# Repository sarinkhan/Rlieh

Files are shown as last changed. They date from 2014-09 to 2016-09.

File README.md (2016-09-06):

Rlieh
=====

Remote Location Intelligent Ecosystem Handler - a system to manage closed ecosystems such as aquariums or terrariums.
This relies on open source and open hardware technologies. It's meant to be modular, not too expensive, and yet powerful.
Feel free to consult the [Rlieh wiki](https://github.com/sarinkhan/Rlieh/wiki) for more!

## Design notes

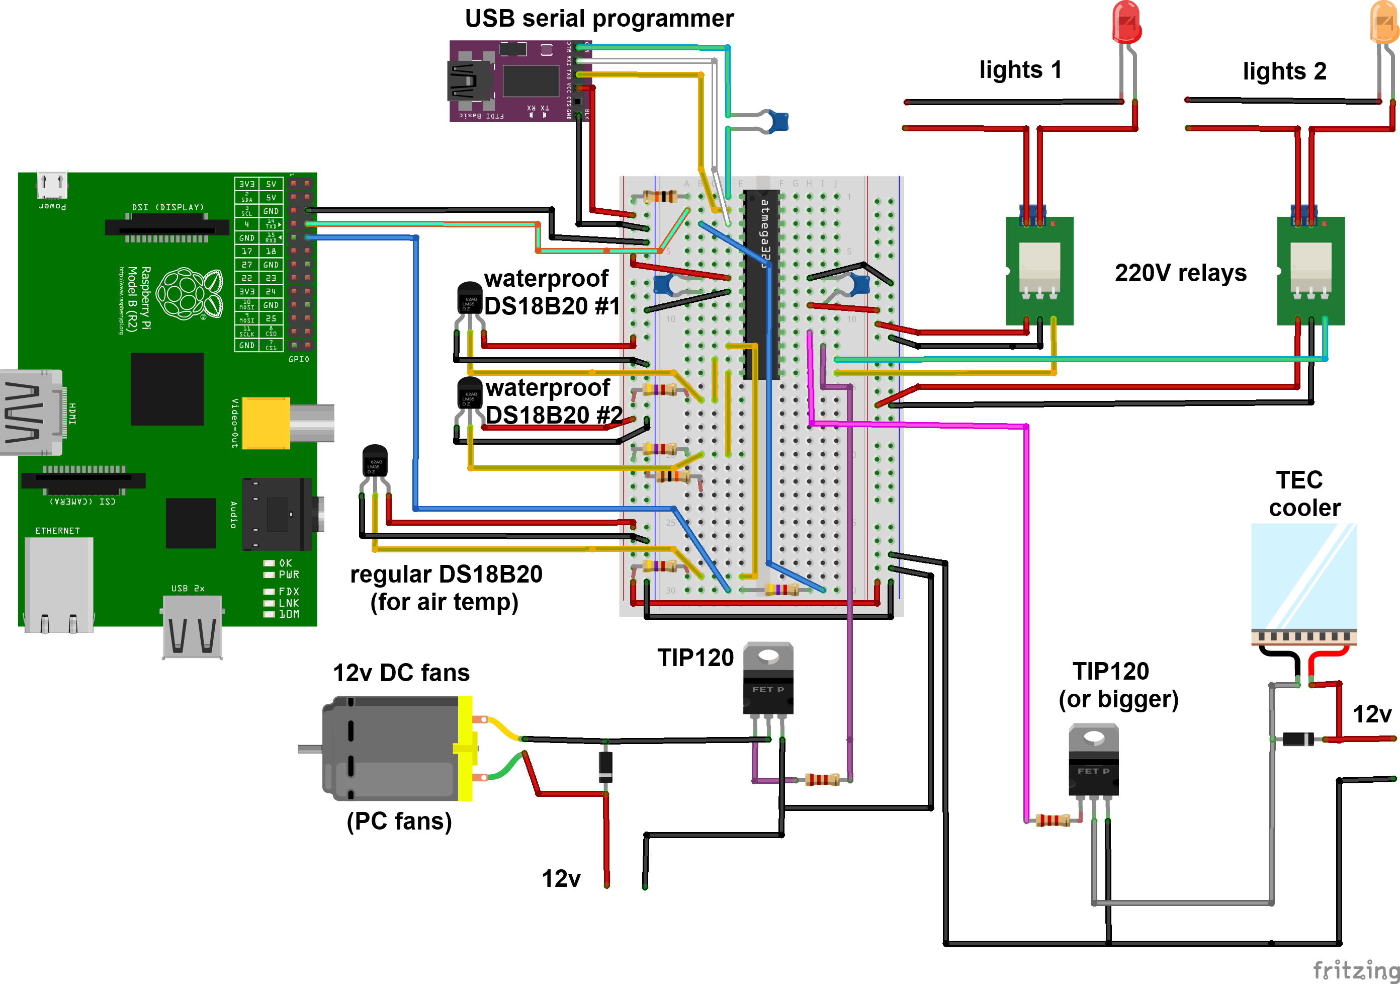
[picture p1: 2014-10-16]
fritzing/base_circuit02_annotations.png

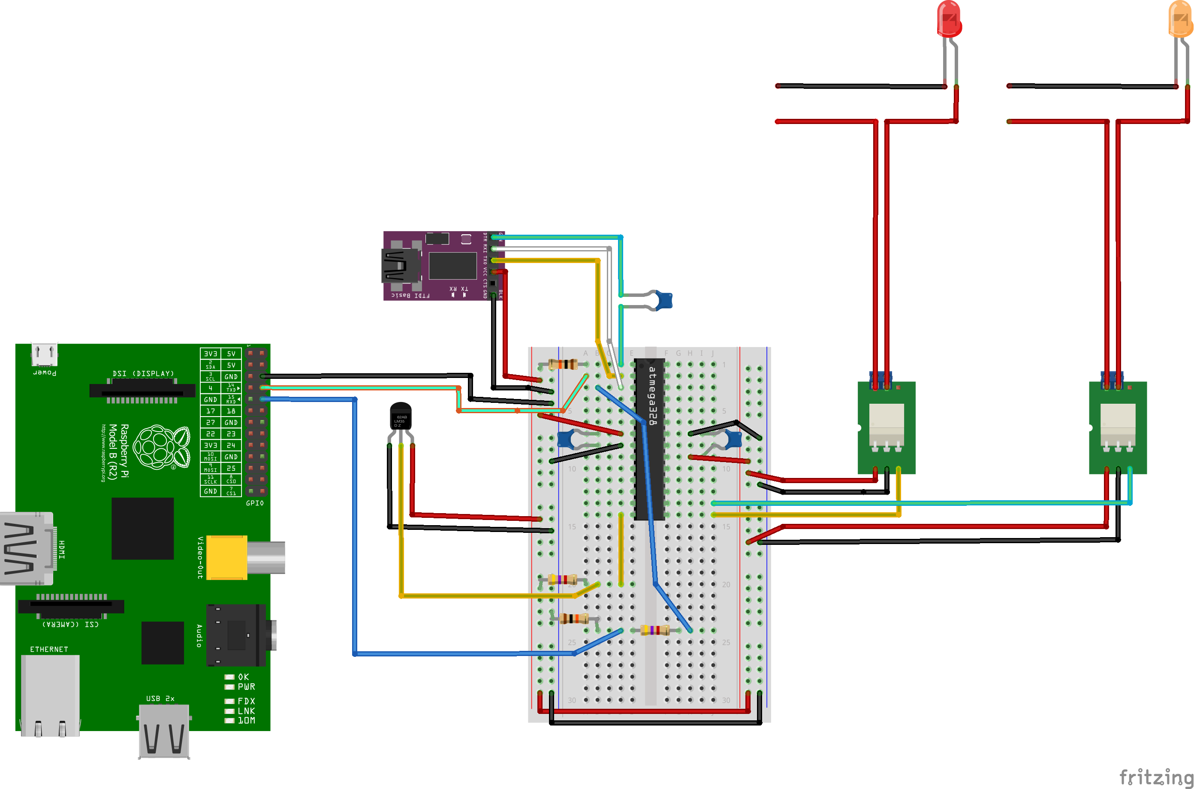
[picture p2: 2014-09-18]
fritzing/base_circuit01.png

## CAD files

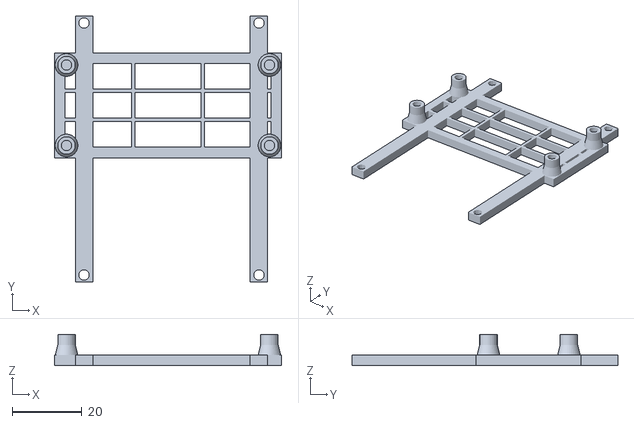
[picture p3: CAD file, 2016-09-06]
enclosure/piZeroSimpleSupportBottom.stl
65.0 x 76.0 x 9.00

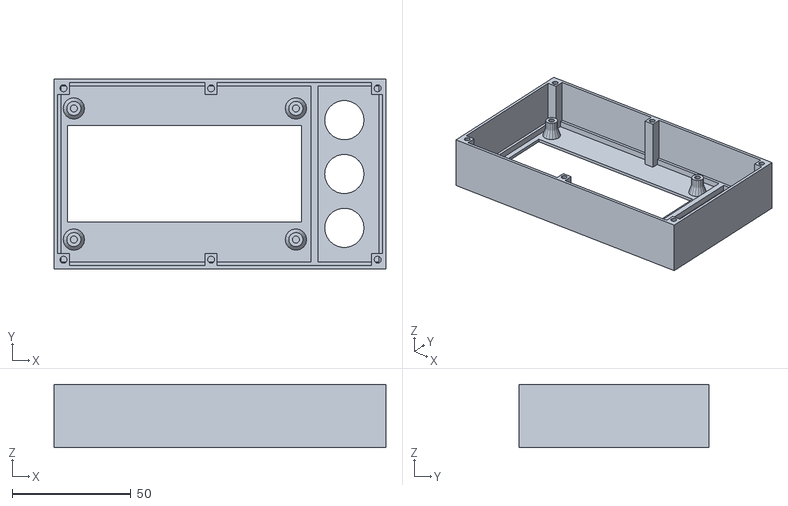
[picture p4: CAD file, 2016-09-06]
enclosure/controlBox.stl
139.5 x 80.0 x 26.5

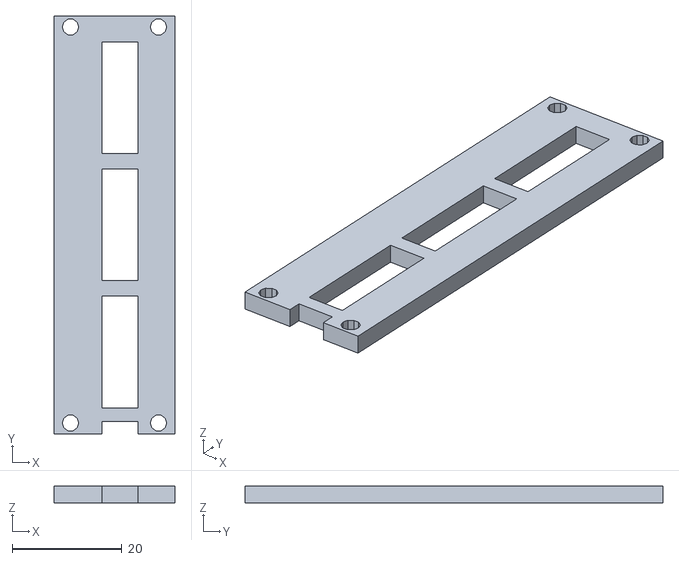
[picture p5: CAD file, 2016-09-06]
enclosure/frontLedsDiffuserCenteringPlate.stl
22.0 x 76.0 x 3.00

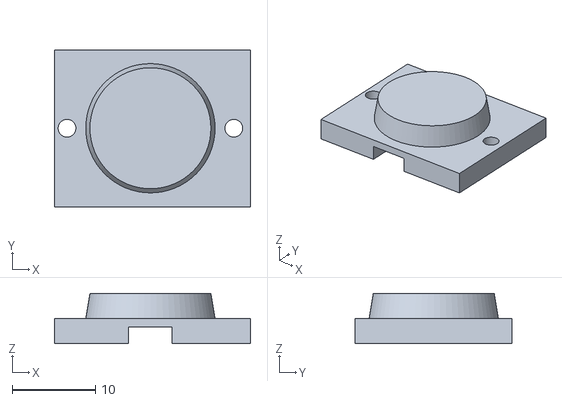
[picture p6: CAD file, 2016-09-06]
enclosure/frontLedDiffuserButton.stl
23.5 x 18.8 x 6.00

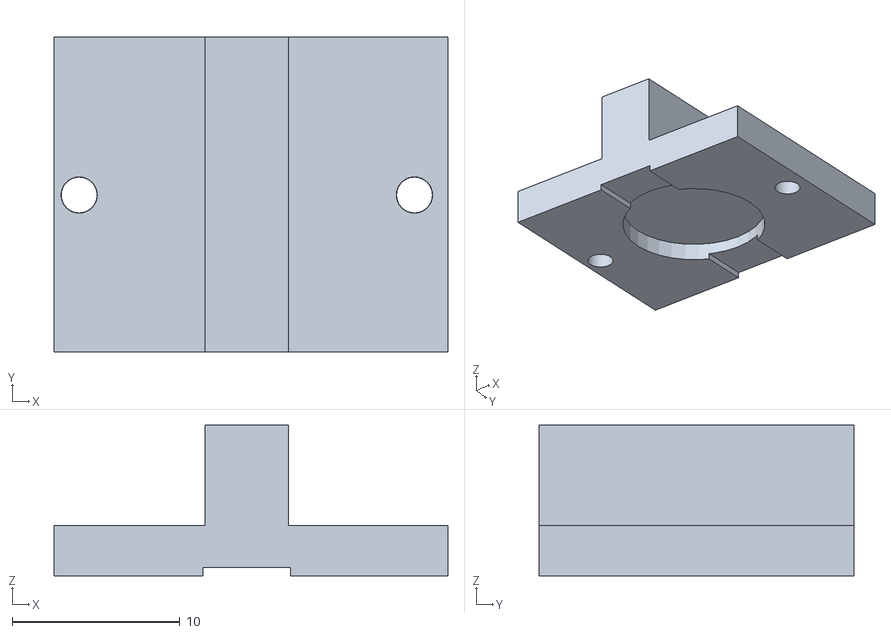
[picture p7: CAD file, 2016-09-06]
enclosure/frontLedDiffuserButtonBack.stl
23.5 x 18.8 x 9.00

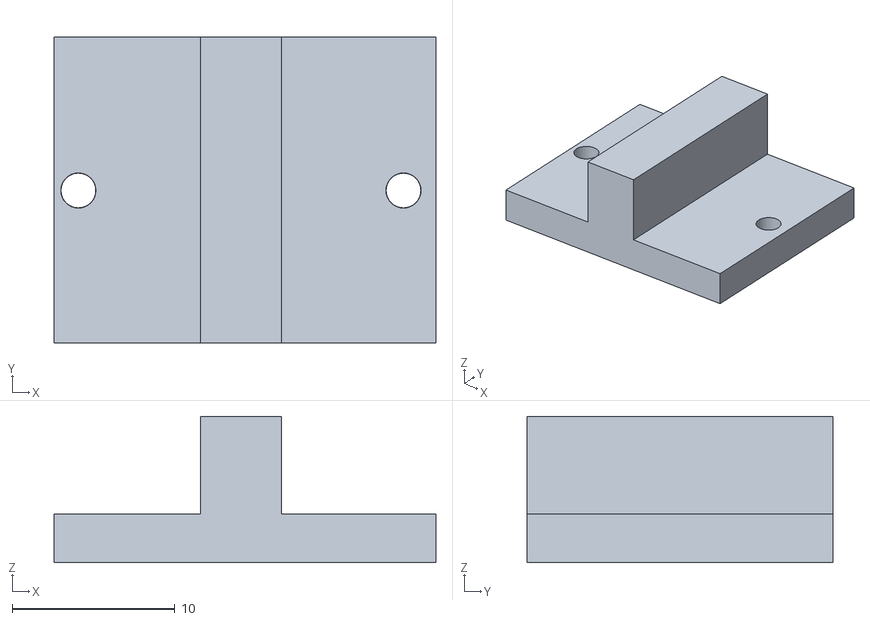
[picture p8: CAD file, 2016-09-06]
enclosure/ledDiffuserBackPlate.stl
23.5 x 18.8 x 9.00

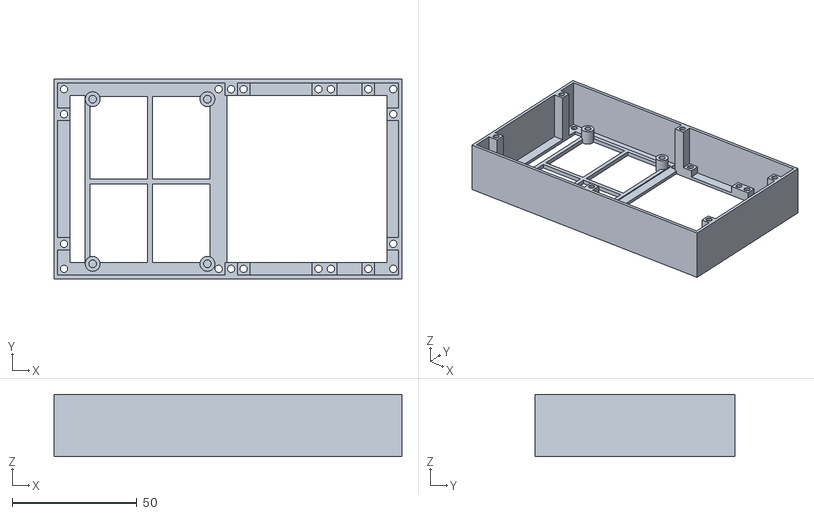
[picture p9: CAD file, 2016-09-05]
enclosure/faceBox_layer2.stl
139.5 x 80.0 x 25.0

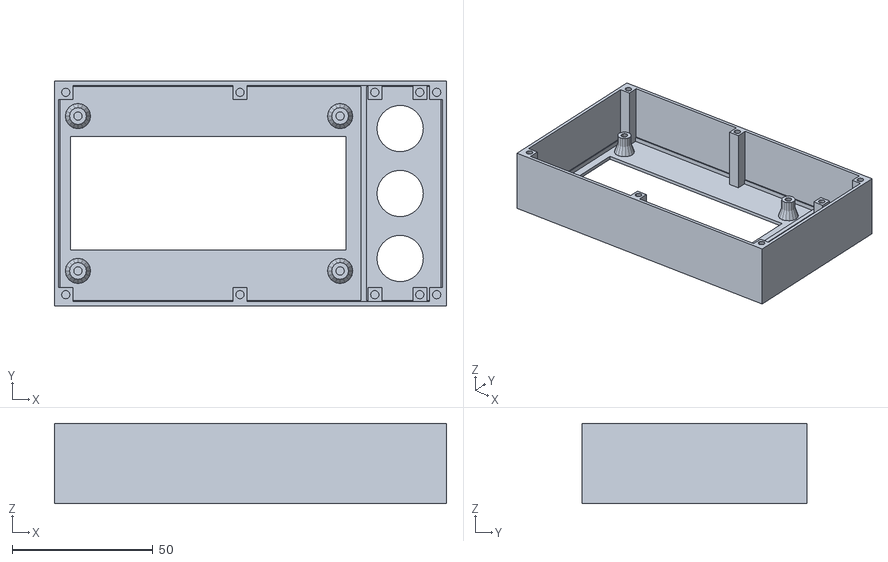
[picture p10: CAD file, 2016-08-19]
enclosure/faceBox.stl
139.5 x 80.0 x 28.5

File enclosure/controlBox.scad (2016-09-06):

include<../parts/textLcdBezels.scad>


//bezel4x20X=110;
bezel4x20Y=80;

boxWallsThickness=1.5;
buttonsAreaX=30;

buttonsHoleRadius=16.5/2;
beamsThickness=3;

boxPart1Z=25;
screwHoles1Radius=3/2;
pillarsWidth1=5;

module fixationPillar(pillarWidth=pillarsWidth1,pillarHeight=boxPart1Z,pillarScrewRadius=screwHoles1Radius)
{
    difference()
    {
    cube([pillarWidth,pillarWidth,pillarHeight]);
        translate([pillarWidth/2,pillarWidth/2,1])
        cylinder(r=pillarScrewRadius,h=pillarHeight,$fn=12);
    } 
}

nbButtons=3;
buttonDecalX=(buttonsAreaX-beamsThickness*2-1)/2;
buttonDecalY=(bezel4x20Y-beamsThickness*2-nbButtons*buttonsHoleRadius*2)/(nbButtons+1);
echo (buttonDecalY);
bezel4x20(bezel4x20X,bezel4x20Y,boxWallsThickness,3/2);
translate([bezel4x20X-0.5,0,0])
{
    difference()
    {
        cube([buttonsAreaX,bezel4x20Y,boxWallsThickness]);
        for(i = [1 : 1 : nbButtons])
        {
            translate([buttonDecalX+1,beamsThickness+buttonDecalY*i+buttonsHoleRadius+buttonsHoleRadius*2*(i-1),-boxWallsThickness/2])
                cylinder(r=buttonsHoleRadius,h=boxWallsThickness*2);
        }
        
        /*translate([buttonDecalX+1,27,-boxWallsThickness/2])
            cylinder(r=buttonsHoleRadius,h=boxWallsThickness*2);
        translate([buttonDecalX+1,55,-boxWallsThickness/2])
            cylinder(r=buttonsHoleRadius,h=boxWallsThickness*2);*/
        
    }
}

//beams
translate([0,0,boxWallsThickness])
    cube([bezel4x20X+buttonsAreaX-0.5,beamsThickness,beamsThickness]);
translate([0,bezel4x20Y-beamsThickness,boxWallsThickness])
    cube([bezel4x20X+buttonsAreaX-0.5,beamsThickness,beamsThickness]);

translate([0,0,boxWallsThickness])
    cube([beamsThickness,bezel4x20Y,beamsThickness]);
translate([bezel4x20X+buttonsAreaX-beamsThickness-0.5,0,boxWallsThickness])
    cube([beamsThickness,bezel4x20Y,beamsThickness]);

translate([bezel4x20X-beamsThickness+1,0,boxWallsThickness])
    cube([beamsThickness,bezel4x20Y,beamsThickness]);

//walls
translate([0,0,boxWallsThickness])
    cube([bezel4x20X+buttonsAreaX-0.5,boxWallsThickness,boxPart1Z]);
translate([0,bezel4x20Y-boxWallsThickness,boxWallsThickness])
    cube([bezel4x20X+buttonsAreaX-0.5,boxWallsThickness,boxPart1Z]);
translate([0,0,boxWallsThickness])
    cube([boxWallsThickness,bezel4x20Y,boxPart1Z]);
translate([bezel4x20X+buttonsAreaX-boxWallsThickness-0.5,0,boxWallsThickness])
    cube([boxWallsThickness,bezel4x20Y,boxPart1Z]);

//pillars
translate([boxWallsThickness,boxWallsThickness,boxWallsThickness])    
    fixationPillar();
translate([bezel4x20X+buttonsAreaX-pillarsWidth1-boxWallsThickness,boxWallsThickness,boxWallsThickness])    
    fixationPillar();


translate([(bezel4x20X+buttonsAreaX)/2-pillarsWidth1-boxWallsThickness,bezel4x20Y-pillarsWidth1-boxWallsThickness,boxWallsThickness])    
    fixationPillar();
translate([(bezel4x20X+buttonsAreaX)/2-pillarsWidth1-boxWallsThickness,boxWallsThickness,boxWallsThickness])    
    fixationPillar();

    
translate([boxWallsThickness,bezel4x20Y-pillarsWidth1-boxWallsThickness,boxWallsThickness])    
    fixationPillar();
translate([bezel4x20X+buttonsAreaX-pillarsWidth1-boxWallsThickness,bezel4x20Y-pillarsWidth1-boxWallsThickness,boxWallsThickness])    
    fixationPillar();

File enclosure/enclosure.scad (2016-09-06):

battSlotsSpacingX=1;
beamsThickness2=5;
firstStageHeight=28;

include<../parts/lipoBattHolder.scad>
include<waterproofBox.scad>
include<../parts/rpiPlate5_halfFlatMount_mod.scad>




//constraints : these are the minimal internal dimensions of the box
insideBoxMinX=basicBattHolderLength;
insideBoxMinY=83+2*beamsThickness2;
insideBoxMinZ=72;




//if you want to alter the box size, change the values here, keeping the min sizes and adding a value : 
insideBoxX1=insideBoxMinX+battSlotsSpacingX*2+25;
insideBoxY1=insideBoxMinY+0;
insideBoxZ1=insideBoxMinZ+0;


boxSealingLipWidth=8;
boxLipThickness=2;




echo ("inside box X : ");
echo(insideBoxX1);
echo ("inside box Y : ");
echo(insideBoxY1);
echo ("inside box Z : ");
echo(insideBoxZ1);

//basicBattHolderWidth
boxWallsThickness1=1;
boxSealingLipWidth=beamsThickness2;
screwHoles1Radius=3/2;



secondStageDecal=0.5;


cameraHoleRadius=20/2;
cameraHoleZDecal=5;
cameraSkirtSupportThickness=7;
cameraSkirtSupportBaseWidth=cameraHoleRadius*2+20;
cameraSkirtSupportBaseHeight=cameraSkirtSupportBaseWidth;
cameraSkirtSupportDecalY=(cameraSkirtSupportBaseWidth-cameraHoleRadius*2)/2;
cameraSkirtSupportDecalZ=(cameraSkirtSupportBaseHeight-cameraHoleRadius*2)/2;
cameraSkirtSupportScrewHolesDistFromEdge=4;

cameraHole=1;   //set to 1 for a camera hole, 0 for no hole

buttonsHoles=1; //set to 1 for button holes, 0 for no hole
buttonsHolesRadius=16.8/2;
buttonsCount1=3;
buttonsMargin1=5;

totalBoundingBoxX=insideBoxX1+2*boxWallsThickness1+2*boxSealingLipWidth;
totalBoundingBoxY=insideBoxY1+2*boxWallsThickness1+2*boxSealingLipWidth;
totalBoundingBoxZ=insideBoxZ1+boxWallsThickness1+0;//define


frontOpeningRadius=buttonsHolesRadius;
frontOpeningsPlateX=cameraSkirtSupportThickness;
frontOpeningsPlateY=frontOpeningRadius*2+10;
frontOpeningsPlateZ=frontOpeningsPlateY;
frontOpeningsholesDistFromEdge=3;
frontOpening1=1;
frontOpening2=1;
frontOpeningDecalZ=firstStageHeight+beamsThickness2+5;


frontOpeningsGasketThickness=1.5;
frontOpeningsLidThickness=4;



sideOpeningRadius=frontOpeningRadius;
sideOpeningsPlateX=frontOpeningsPlateX;
sideOpeningsPlateY=frontOpeningsPlateY;
sideOpeningsPlateZ=frontOpeningsPlateZ;
sideOpeningsholesDistFromEdge=frontOpeningsholesDistFromEdge;
sideOpening1=1;
sideOpening2=1;
sideOpeningDecalZ=frontOpeningDecalZ;


backOpenings1=1;
backOpenings2=1;
backOpeningsCount=3;
backOpeningRadius=frontOpeningRadius;
backOpeningsPlateX=frontOpeningsPlateX;
backOpeningsPlateY=frontOpeningsPlateY;
backOpeningsPlateZ=frontOpeningsPlateZ;
backOpeningsholesDistFromEdge=frontOpeningsholesDistFromEdge;
backOpening1DecalZ=frontOpeningDecalZ;
backOpening2DecalZ=2;
backOpenings1Count=3;
backOpenings2Count=3;



/**
 * This module constructs a circular opening with a support base, and 4 screwholes in each corner
 */
module openingWithSupport1(centralOpeningRadius=buttonsHolesRadius,frFixHolesRad=screwHoles1Radius,baseX,baseY,baseZ,holesDistFromEdge)
{
    difference()
    {
        cube([baseX,baseY,baseZ]);
        translate([-baseX/2,baseY/2,baseZ/2])
            rotate([0,90,0])
                cylinder(r=centralOpeningRadius,h=baseX*2,$fn=64);
        
       translate([-baseX/2,holesDistFromEdge,holesDistFromEdge])
            rotate([0,90,0])
                cylinder(r=frFixHolesRad,h=baseX*2,$fn=16);
       translate([-baseX/2,baseY-holesDistFromEdge,holesDistFromEdge])
            rotate([0,90,0])
                cylinder(r=frFixHolesRad,h=baseX*2,$fn=16);
       translate([-baseX/2,holesDistFromEdge,baseZ-holesDistFromEdge])
            rotate([0,90,0])
                cylinder(r=frFixHolesRad,h=baseX*2,$fn=16);
       translate([-baseX/2,baseY-holesDistFromEdge,baseZ-holesDistFromEdge])
            rotate([0,90,0])
                cylinder(r=frFixHolesRad,h=baseX*2,$fn=16);
    }
}
module openingWithSupport1WithSlope(centralOpeningRadius=buttonsHolesRadius,frFixHolesRad=screwHoles1Radius,baseX,baseY,baseZ,holesDistFromEdge)
{
   openingWithSupport1(centralOpeningRadius,frFixHolesRad,baseX,baseY,baseZ,holesDistFromEdge);
    translate([baseX,baseY,0])
            rotate([90,-180,0])
                triangleSupport(baseX,baseX,baseY);
    
}

module openingLid(frFixHolesRad=screwHoles1Radius,baseX,baseY,baseZ,holesDistFromEdge)
{
    difference()
    {
        cube([baseX,baseY,baseZ]);
       translate([-baseX/2,holesDistFromEdge,holesDistFromEdge])
            rotate([0,90,0])
                cylinder(r=frFixHolesRad,h=baseX*2,$fn=16);
       translate([-baseX/2,baseY-holesDistFromEdge,holesDistFromEdge])
            rotate([0,90,0])
                cylinder(r=frFixHolesRad,h=baseX*2,$fn=16);
       translate([-baseX/2,holesDistFromEdge,baseZ-holesDistFromEdge])
            rotate([0,90,0])
                cylinder(r=frFixHolesRad,h=baseX*2,$fn=16);
       translate([-baseX/2,baseY-holesDistFromEdge,baseZ-holesDistFromEdge])
            rotate([0,90,0])
                cylinder(r=frFixHolesRad,h=baseX*2,$fn=16);
    }
}

module cameraSkirtBaseShape()
{
    openingWithSupport1(buttonsHolesRadius,screwHoles1Radius,cameraSkirtSupportThickness,cameraSkirtSupportBaseWidth,cameraSkirtSupportBaseHeight,cameraSkirtSupportScrewHolesDistFromEdge);
}

module cameraSkirt()
{
    cameraSkirtBaseShape();
}


module cameraSkirtBaseShapeWithSlope()
{
    cameraSkirtBaseShape();
    translate([cameraSkirtSupportThickness,cameraSkirtSupportBaseWidth,0])
            rotate([90,-180,0])
                triangleSupport(cameraSkirtSupportThickness,cameraSkirtSupportThickness,cameraSkirtSupportBaseWidth);
}
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

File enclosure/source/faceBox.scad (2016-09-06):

include<textLcdBezels.scad>
use<rpiPlateCompact1.scad>





//bezel4x20X=110;
bezel4x20Y=80;

boxWallsThickness=1.5;
buttonsAreaX=30;

buttonsHoleRadius=16.5/2;         
beamsThickness=3;

boxPart1Z=27;
boxPart2Z=25;
boxPart3Z=25;
screwHoles1Radius=3/2;
pillarsWidth1=5;

/*
battBoxX=100;
battBoxY=95;
battBoxWallsThickness=1;

battBoxWallsHeight=20;
battBoxWalls2Height=30;
*/

fixationBeamsThickness=5;
fixationBeamsHolesRadius=3/2;

/*
pcbX=40;
pcbY=60;*/

pcbHolesDistFromEdge=2;

beamsThickness=2.0;
circuit1X=50;
circuit1Y=70;
circuit1ScrewsRadius=2/2;
circuit1ScrewsDistFromEdge=1;
circuit1ScrewPillarsH=5+beamsThickness;
screwHolesRadius=2/2;
padding=0.1;

buttonPlatePillarsHeight=8;

alertBoxExternalX=bezel4x20X+buttonsAreaX-0.5;
alertBoxInternalX1=alertBoxExternalX-boxWallsThickness*2;
alertBoxInternalX2=alertBoxInternalX1-pillarsWidth1*2;

alertBoxExternalY=bezel4x20Y;
alertBoxInternalY1=alertBoxExternalY-boxWallsThickness*2;
alertBoxInternalY2=alertBoxInternalY1-pillarsWidth1*2;

boxInternalPadding=0.5;





nbButtons=3;
buttonDecalX=(buttonsAreaX-beamsThickness*2-1)/2;
buttonDecalY=(bezel4x20Y-beamsThickness*2-nbButtons*buttonsHoleRadius*2)/(nbButtons+1);
echo (buttonDecalY);

diffuserCentralHoleR=7.2/2;
    diffuserCentralHoleR2=12/2;
    diffuserLedCompartmentDepth=2;
    diffuserWireChanelWidth=5.2;
    diffuserBaseX=buttonsAreaX-1-5-0.5;
    diffuserBaseY=buttonsHoleRadius*2+buttonDecalY/2-1;
    diffuserBaseThickness=3;
    diffuserButtonCylinderZ=3;

    diffuserBackPlateFootX=5;
    diffuserBackPlateFootY=diffuserBaseY;
    diffuserBackPlateFootZ=6;
    
    
    piZeroHolesDistFromEdge=3.5;
    piZeroHolesRadius=2.75/2;
    
    piZeroLongSideHolesDist=58;
    piZeroShortSideHolesDist=23;
    
    piZeroLongSide=65;
    piZeroShortSide=30;
    
    
    
    module genericStandoff(holeRadius=3/2,standoffThickness=1,footHeight=3,footMultiplier=1.3,standoffTotalHeight=6,baseFootThickness=0,fn=32)
    {
        difference()
        {
        union()
        {
            translate([0,0,baseFootThickness])
            {
            cylinder(r1=(holeRadius+standoffThickness)*footMultiplier, r2=(holeRadius+standoffThickness),h=footHeight,$fn=fn);
            cylinder(r=(holeRadius+standoffThickness),h=standoffTotalHeight,$fn=fn);
            }
            if(baseFootThickness>0)
            {
                cylinder(r=(holeRadius+standoffThickness)*footMultiplier,h=baseFootThickness,$fn=fn);
            }
        }
        translate([0,0,baseFootThickness])
        cylinder(r=holeRadius,h=standoffTotalHeight+1,$fn=fn);
    }
        
    }
    
    
    //genericStandoff(baseFootThickness=3);
    
    
    module genericSupportFrame(outerFrameX,outerFrameY,frameThickness=3,frameBracesCountX=2,frameBracesCountY=2,framebracesThickness=1)
    {
        cube([outerFrameX,frameThickness,frameThickness]);
        cube([frameThickness,outerFrameY,frameThickness]);
        translate([0,outerFrameY-frameThickness,0])
            cube([outerFrameX,frameThickness,frameThickness]);
        translate([outerFrameX-frameThickness,0,0])
            cube([frameThickness,outerFrameY,frameThickness]);
        
        insideFrameFreeSpaceX=outerFrameX-(frameThickness*2)-frameBracesCountX*framebracesThickness;
        bracesSpacingX=insideFrameFreeSpaceX/(frameBracesCountX+1);
        
        if(frameBracesCountX>0)
        {
            for (i =[1:frameBracesCountX])
            {
                translate([frameThickness+(bracesSpacingX)*i+framebracesThickness*(i-1),0,0])
                    cube([framebracesThickness,outerFrameY,frameThickness]);
            }
        }
        
        insideFrameFreeSpaceY=outerFrameY-(frameThickness*2)-frameBracesCountY*framebracesThickness;
        bracesSpacingY=insideFrameFreeSpaceY/(frameBracesCountY+1);
        
        if(frameBracesCountY>0)
        {
            for (i =[1:frameBracesCountY])
            {
                translate([0,frameThickness+(bracesSpacingY)*i+framebracesThickness*(i-1),0])
                    cube([outerFrameX,framebracesThickness,frameThickness]);
            }
        }
    }
    
    module piZeroSimplePlate(frameThickness1=3,frameBracesCountX1=2,frameBracesCountY1=2,framebracesThickness1=1)
    {
        genericSupportFrame(outerFrameX=piZeroLongSide,outerFrameY=piZeroShortSide,frameThickness=frameThickness1,frameBracesCountX=frameBracesCountX1,frameBracesCountY=frameBracesCountY1,framebracesThickness=framebracesThickness1);
        
        
        
        translate([piZeroHolesDistFromEdge,piZeroHolesDistFromEdge,0])
        genericStandoff(baseFootThickness=frameThickness1);
        
        translate([piZeroHolesDistFromEdge,piZeroHolesDistFromEdge+piZeroShortSideHolesDist,0])
        genericStandoff(baseFootThickness=frameThickness1);
        
        translate([piZeroHolesDistFromEdge+piZeroLongSideHolesDist,piZeroHolesDistFromEdge,0])
        genericStandoff(baseFootThickness=frameThickness1);
        
        translate([piZeroHolesDistFromEdge+piZeroLongSideHolesDist,piZeroHolesDistFromEdge+piZeroShortSideHolesDist,0])
        genericStandoff(baseFootThickness=frameThickness1);
    }

    //genericSupportFrame(outerFrameX=60,outerFrameY=30);
    








module fixationPillar(pillarWidth=pillarsWidth1,pillarHeight=boxPart1Z,pillarScrewRadius=screwHoles1Radius)
{
    difference()
    {
    cube([pillarWidth,pillarWidth,pillarHeight]);
        translate([pillarWidth/2,pillarWidth/2,1])
        cylinder(r=pillarScrewRadius,h=pillarHeight,$fn=12);
    } 
}

module openBasePlate(x,y,nbBeamsX=3,nbBeamsY=2)
{
	xShift=x/(nbBeamsX+1);
	for (i =[0:nbBeamsX+1])
	{
		translate([xShift*i,0,0])
			cube([beamsThickness,y,beamsThickness]);
	}


	yShift=y/(nbBeamsY+1);
	for (i =[0:nbBeamsY+1])
	{
		translate([0,yShift*i,0])
			cube([x+beamsThickness,beamsThickness,beamsThickness]);
	}
}
module motorBracketHole(h0=boxPart1Z-beamsThickness,shift=beamsThickness,r0=screwHolesRadius) 
{
	translate([0,0,padding+shift]) 
	{
    	cylinder(r=3.1/2, h0+padding, center = false,$fn=32);
	}
}

module circuit1Plate()
{

	openBasePlate(circuit1X,circuit1Y,1,1);
    
    rrr0=3;

	translate([beamsThickness+circuit1ScrewsDistFromEdge,beamsThickness+circuit1ScrewsDistFromEdge,0])
		difference()
		{
			cylinder(r=rrr0,h=circuit1ScrewPillarsH,$fn=32);
			motorBracketHole();
		}

	translate([beamsThickness+circuit1ScrewsDistFromEdge,circuit1Y-circuit1ScrewsDistFromEdge,0])
		difference()
		{
			cylinder(r=rrr0,h=circuit1ScrewPillarsH,$fn=32);
			motorBracketHole();
		}

	translate([circuit1X-circuit1ScrewsDistFromEdge,beamsThickness+circuit1ScrewsDistFromEdge,0])
		difference()
		{
			cylinder(r=rrr0,h=circuit1ScrewPillarsH,$fn=32);
			motorBracketHole();
		}

	translate([circuit1X-circuit1ScrewsDistFromEdge,circuit1Y-circuit1ScrewsDistFromEdge,0])
		difference()
		{
			cylinder(r=rrr0,h=circuit1ScrewPillarsH,$fn=32);
			motorBracketHole();
		}
}



module ledDiffuser()
{
    translate([bezel4x20X-0.5,0,0])
{
  
        for(i = [1 : 1 : 1])
        {
            translate([buttonDecalX+1,beamsThickness+buttonDecalY*i+buttonsHoleRadius+buttonsHoleRadius*2*(i-1),0])
                cylinder(r1=buttonsHoleRadius-1,r2=buttonsHoleRadius-0.5,h=diffuserButtonCylinderZ,$fn=64);
        }
        difference()
        {
        translate([2,pillarsWidth1+beamsThickness+0.5,diffuserButtonCylinderZ])
        //#cube([buttonsAreaX-1-5,bezel4x20Y-pillarsWidth1*2-boxWallsThickness*2-1,boxWallsThickness*2]);
    cube([diffuserBaseX,diffuserBaseY,diffuserBaseThickness]);      
            translate([buttonDecalX+1,beamsThickness+buttonDecalY*1+buttonsHoleRadius+buttonsHoleRadius*2*(1-1),diffuserButtonCylinderZ])
            cylinder(r1=diffuserCentralHoleR,r2=diffuserCentralHoleR2,h=diffuserBaseThickness+0.5,$fn=32);
            
            
    translate([buttonDecalX+1-diffuserCentralHoleR2-4,beamsThickness+buttonDecalY*1+buttonsHoleRadius+buttonsHoleRadius*2*(1-1),boxWallsThickness-1])
            cylinder(r=1.05,r2=1.1,h=diffuserLedCompartmentDepth*4,$fn=32);
            
    translate([buttonDecalX+1+diffuserCentralHoleR2+4,beamsThickness+buttonDecalY*1+buttonsHoleRadius+buttonsHoleRadius*2*(1-1),boxWallsThickness-1])
            cylinder(r=1.05,r2=1.1,h=diffuserLedCompartmentDepth*4,$fn=32);
        
    translate([buttonDecalX+1-diffuserWireChanelWidth/2,beamsThickness+buttonDecalY*1+buttonsHoleRadius+buttonsHoleRadius*2*(1-1)-diffuserBaseX/2,diffuserButtonCylinderZ+diffuserButtonCylinderZ-2])    
           cube([diffuserWireChanelWidth,diffuserBaseX+2,boxWallsThickness+1]);
            //translate([buttonDecalX+1-7/2,beamsThickness+buttonDecalY*1+buttonsHoleRadius+buttonsHoleRadius*2*(1-1)-7/2,boxWallsThickness*2])
            //cube([7,7,boxWallsThickness+1]);
        }

}
}
module ledDiffuserBackPlate()
{
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

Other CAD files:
enclosure/source/rpiPlateCompact1.scad
enclosure/source/textLcdBezels.scad

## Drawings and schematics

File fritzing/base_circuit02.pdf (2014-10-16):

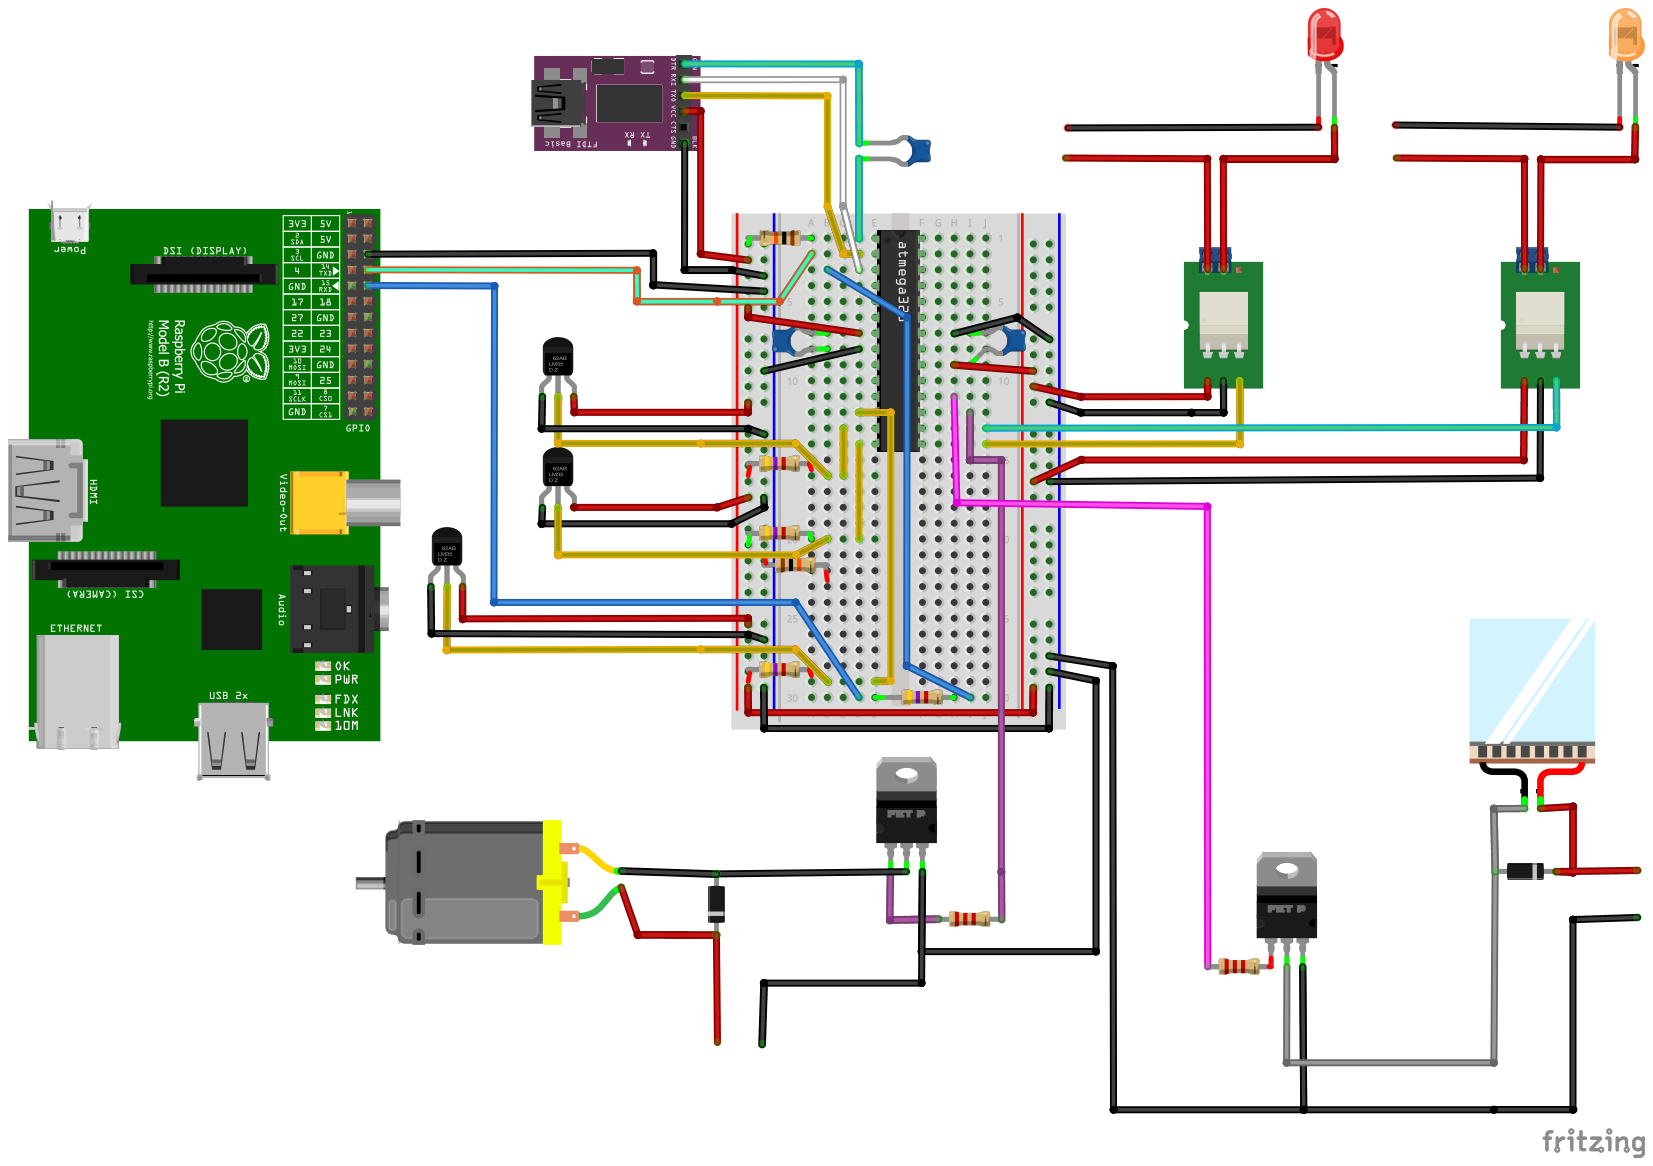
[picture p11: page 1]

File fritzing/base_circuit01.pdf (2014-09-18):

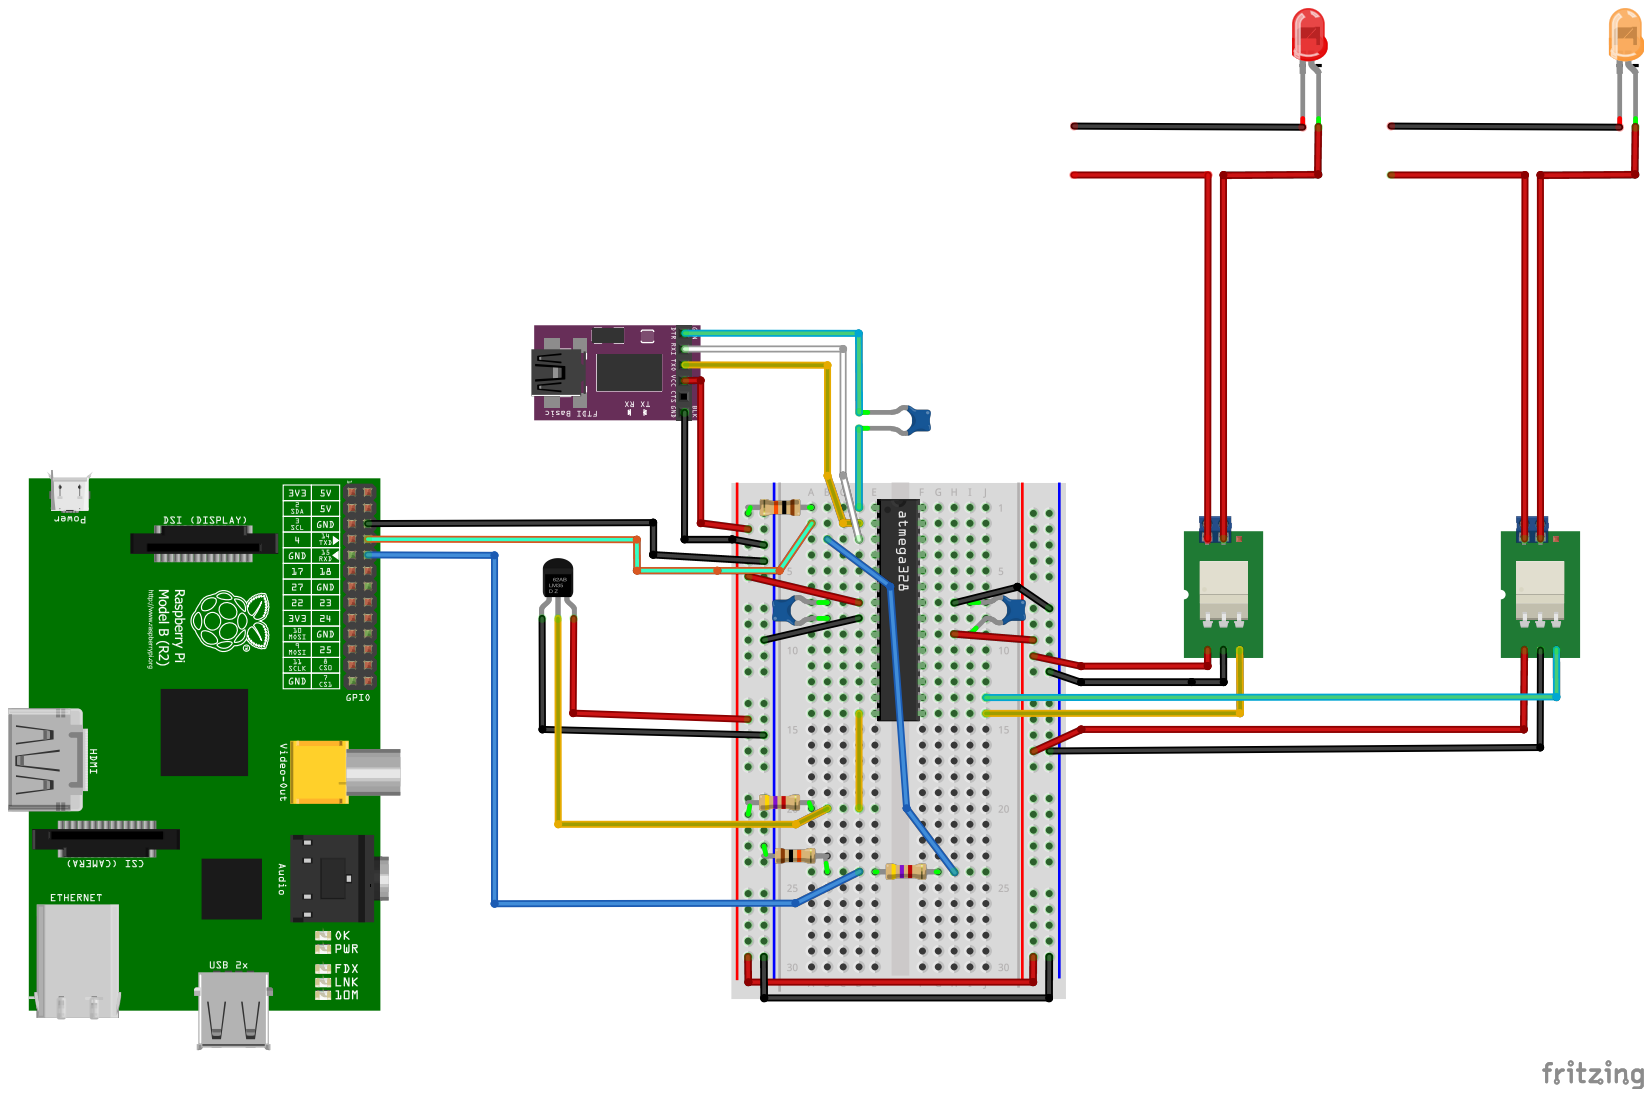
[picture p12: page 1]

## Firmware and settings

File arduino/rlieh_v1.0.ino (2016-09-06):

/**
 * This program manages Rlieh (Remote Location Intelligent Ecosystem Handler)
 * It is meant to automatically control an aquarium, terrarium, or another closed ecosystem.
 * It manages lights, measures temperatures, and monitors parameters. It can work on it's own
 * on an Arduino compatible chip, or can work with any serial capable device, using the uart 
 * port to communicate, send and recieve data.
 * Made by Audrey Robinel
 * GNU GPL V3
 * 
 * program version 1.0
 */

#include <Wire.h> 
#include <OneWire.h>
#include <DallasTemperature.h>
#include <LiquidCrystal_I2C.h>
#include "RTClib.h"

#define AUTO 0            //fully auto mode
#define MANAGED 1         //managed by the pi
#define TEMPO_MANAGED 2   //temporarily managed by the pi


//variables for automatic light management
int lightsMode = AUTO;
int lightOnHour=10;
int lightOffHour=22;



int lightsTemporaryMangedTimeOut=3600;//time for temporary management, in seconds
unsigned long lightsTemporaryManagedStartTime=0;//temporary management start time, used to revert to auto mode after some time

int lcdMode = AUTO;
int lcdTemporaryManagedTimeOut=60;//time for temporary management, in seconds
unsigned long lcdTemporaryManagedStartTime=0;//temporary management start time, used to revert to auto mode after some time


#define LCD_LINES 4
#define LCD_COLS 20


//constants for the verbosity level
#define SILENT 0 //no outputs at all
#define NORMAL 1 //only outputs planed outputs (answers to questions asked on uart)
#define ERRORS 2 //same as the previous, and also outputs error messages.
#define DEBUG 3  //All the previous outputs are kept, but also prints messages for most actions, even successful ones.

//defines the verbosity of the device over the serial port. The higher the number, the more it chats.
int verbosity = NORMAL;

LiquidCrystal_I2C lcd(0x27,LCD_COLS,LCD_LINES);// set the LCD address to 0x27 for a 20 chars and 4 line display
RTC_DS1307 rtc;
int DS18S20_Pin = 2;            //The GPIO where are connected the DS18B20 temperature sensors
OneWire ds(DS18S20_Pin);        

DallasTemperature tSensors(&ds);//temp sensors instantiation

#define NB_TRANSISTORS 4        //number of PWM capable output transistors
#define NB_TEMP_SENSORS 4       //Maximum number of connected temperature sensors


int lightsSlowFadeTime=7000;
int lightsQuickFadeTime=100;

int lightsFadeDefaultTime=lightsSlowFadeTime;    //how long to wait before the next pwm rate modification, in ms
const int lightsPins[4]={3,5,6,9};               //GPIO where are connected the transistors that controls the lights, must be PWM pins.
int lightsStatus[4]={0,0,0,0};                   //Light status. 0=off, 1= on.
int lightsFade[4]={0,0,0,0};                     //The fading status. 0 = no fade, -1 = fade out, 1 = fade in.
int lightsFadeAmount[4]={1,1,1,1};               //By how much do we change the PWM rate each time.
int lightsFadeTime[4]={lightsFadeDefaultTime,lightsFadeDefaultTime,lightsFadeDefaultTime,lightsFadeDefaultTime};//fade time for each light, in ms
int lightsLevel[4]={0,0,0,0};                    // current light level for each light.
int lightsMaxLevel[4]={255,255,255,255};         // the maximum light level (255= fully on, 0= fully off)
unsigned long lightsLastChange[4]={0,0,0,0};     // when the correponding light's level was last updated.




unsigned long currTime=0;

//variables used when pushing the button 1 to bypass certain automated actions.
long bypassTimerDuration=300; //the duration of the bypass due to the button
int bypassTimer=0;            //what is this? should be checked, seems redundant with the next variable
long bypassStartTime=0;       //when we did start to bypass

long debounceDelay = 50;    // the debounce time for the buttons. 

//variables for the first button
const int button1Pin=4;
long lastDebounceTime1 = 0; // the last time the output pin was toggled
int button1State; 
int lastButton1State = HIGH;

//variables for the second, yet unused button.
const int button2Pin=13;
long lastDebounceTime2 = 0; // the last time the output pin was toggled
int button2State; 
int lastButton2State = HIGH;

int backLightStatus=LOW;

int printedLightStatus=0;   //tells if the light status has been printed or not.

int lastTimeReadTemp=0;
float airTemp=0.0;
float waterTemp1=0.0;
float waterTemp2=0.0;

float TC[4]={-127.0,-127.0,-127.0,-127.0};


int  DS18B20resolution = 12;
DeviceAddress tempDeviceAddress;

const char separator=':';//separator for multiple args , and to separate the command from args.
const int cmdLength=5;   //the size, in chars, of the command.

//lcd commands constants
const int colLength=2;
const int rowLength=2;

//led commands constants
const int ledIdLength=2;
const int colorLength=3;

//temp  commands constants
const int tempProbeIdLength=2;
const int lightIdLength=2;

//serial port constants
const long serialSpeed=115200;  //serial speed. 1
const int serialTimeout=10;     //the timeout for the serial terminal. If too high, it will slow down the PWM changes, since the loop function will wait that much time on each pass. 10 works at 250000 speed.


//-------------------------------------------------------------//
//----------------------------SETUP----------------------------//
//-------------------------------------------------------------//
/**
 * This function initializes the LCD, sets the terminal speed and timeout,a few prints on the LCD,
 * pinmodes for a few pins of the Arduino, initializes the sensors, and a few other variables.
 */
void setup()
{
  lcd.init();// initialize the lcd
  //Serial.begin(500000);
  Serial.begin(serialSpeed);
  Serial.setTimeout(serialTimeout);
  if(verbosity>ERRORS)
        {Serial.println("Rlieh V1.0");}
  lcd.backlight();
  lcd.setCursor(0, 0);
  lcd.print("Rlieh V1.0");

  rtc.begin();
  
  pinMode(button1Pin, INPUT_PULLUP);
  pinMode(button2Pin, INPUT_PULLUP);

  int i=0;
  for(i=0;i<NB_TRANSISTORS;i++)
  {
    pinMode(lightsPins[i],OUTPUT);
    analogWrite(lightsPins[i],lightsLevel[i]);
    lightsLastChange[i]=millis();
  }

  tSensors.begin();
  for(i=0;i<NB_TRANSISTORS;i++)
  {
    tSensors.getAddress(tempDeviceAddress, i);
    tSensors.setResolution(tempDeviceAddress, DS18B20resolution);
  }

  tSensors.setWaitForConversion(false); //set non blocking mode
  tSensors.requestTemperatures();       //asks for temperature readings
  lastTimeReadTemp=millis();            //initializes the timestamp of the last read temperature

}

//-------------------------------------------------------------//
//----------------------------LOOP-----------------------------//
//-------------------------------------------------------------//
/**
 * The main loop of the arduino reads a string from the serial terminal, and passes the string
 * to the parseCMD function (that will mostly return things through the serial port, update flags
 * or variables).
 * 
 * The loop function then lanches the fadeLights function for each transistor, and fetches the values
 * returned by the sensors.
 * 
 * it also monitors a button, and if pressed, it starts the lights if off, or turn it off if it was up.
 * If the button is not pressed, it checks if some timed commands are finished and changes automated modes
 * accordingly. Note that in managed mode, this part is ignored.
 * 
 * Depending on the mode, it also manages automated printing on the screen (if in automated screen mode).
 */
void loop()
{
   String s=Serial.readString();      //reads a string from serial (UART)
  
   if(verbosity>ERRORS)
        {Serial.println(s);}
        
   parseCMD(s);                       //parses the command and acts accordingly
   
   int i=0;
   for(i=0;i<NB_TRANSISTORS;i++)
   {
    fadeLights(i);//this updates the lights PWM level if they are fading 
   }
  
   if(millis()-lastTimeReadTemp>800)          //reading sensors takes 800ms, so if more time has elapsed since last read, we get the values
   {

    for(i=0;i<NB_TEMP_SENSORS;i++)
      {TC[i]=tSensors.getTempCByIndex(i);}  //we store the temperature of each sensors

    tSensors.requestTemperatures();         //request for another read
    lastTimeReadTemp=millis();              //and reset the timer to current time
   }

   //this part is legacy, and handles button 1, but it's likely to change
   int readingB1 = digitalRead(button1Pin); //read the button
   if (readingB1 != lastButton1State) 
   {
    lastDebounceTime1 = millis(); //debouncint stuff
   }
   
   if ((millis() - lastDebounceTime1) > debounceDelay) //more debouncint stuff
   {
    if (readingB1 != button1State) 
    {
      button1State = readingB1;
      
      if (button1State == LOW) //if the button was pressed (it's a pull up, so pressed is LOW)
      {
        bypassTimer=1;        //we bypass the automated timed stuff
        
        for(i=0;i<NB_TRANSISTORS;i++)
          {lightsFadeTime[i]=lightsQuickFadeTime;} //we define the fade time as the fast value

          
        //backLightStatus = !backLightStatus;         //we also invert the backlight
        bypassStartTime=millis();                   //and record when we started bypassing the automated timers


        for(i=0;i<NB_TRANSISTORS;i++)               //this applies the following changes to all lights
         {
            if(lightsFade[i]==1)//if lights fading in
            {
              setLightsFadeOut(i);  //set to fade out
              backLightStatus=LOW;
            }
            else if(lightsFade[i]==-1)//else if lights fading out
            {
              setLightsFadeIn(i);     //set to fade in
              backLightStatus=HIGH;
            }
            else if(lightsLevel[i]<lightsMaxLevel[i])//else if lights not fading, but not fully on
            {
              setLightsFadeIn(i); //finish fading in
              backLightStatus=HIGH;
            }
            else//else : lights not fading and fully on
            {
              setLightsFadeOut(i); // fade out
              backLightStatus=LOW;
            }  
         }
         
      }
      
    }
    
  }//end debounced push button management
  
  lastButton1State = readingB1;
  DateTime now = rtc.now();
  if(lcdMode==AUTO)//if in auto mode, we can print the temperature
  {
  //this manages the backight, according to the backLightStatus variable
    if(backLightStatus==LOW)
    {
      lcd.noBacklight();
    }
    else
    {
      lcd.backlight();
    }
    currTime=millis();
    
    
    if(LCD_LINES>=4)
    {
    printTimeOnLCD(lcd,3,0);  // prints the time in a consistant format
    lcd.print("  ");
    printDateOnLCD(lcd,3,10); //prints the date on an also consistant format
    lcd.setCursor(0, 1);
    }

  
    //this section prints the temperatures if a probe is connected.
    for(i=0;i<NB_TEMP_SENSORS;i++)
    {
      TC[i]=tSensors.getTempCByIndex(i);
      if(i==2)
      {
        lcd.setCursor(0, 2);
      }
      if(TC[i]>-126)
      {
        lcd.print("T");
        lcd.print(i+1);
        lcd.print(":");
        lcd.print(TC[i]);
        lcd.print(" ");
      }
    }
  }

  
  if(bypassTimer==0)//if we are not bypassing the automated timers
  {
    
    if(lightsMode==AUTO) //if in automated mode
    {
      if(now.hour()>=lightOnHour && now.hour()<lightOffHour)
      {
        for(i=0;i<NB_TRANSISTORS;i++)
          {setLightsFadeIn(i);}
        backLightStatus = HIGH;
      }
      else
      {
        backLightStatus = LOW;
        for(i=0;i<NB_TRANSISTORS;i++)
          {setLightsFadeOut(i);}
      }
    }
  }
  else
  {
    if(millis()>bypassStartTime+bypassTimerDuration*1000)
    {
      bypassTimer=0;
      for(i=0;i<NB_TRANSISTORS;i++)
      {
        lightsFadeTime[i]=lightsSlowFadeTime;
        if(verbosity>ERRORS)
          {Serial.println("revert to slow fade time");}
      }
    }
  }

  if(lightsMode==TEMPO_MANAGED) //if in temporary managed mode
  {
    if(millis()>lightsTemporaryManagedStartTime+lightsTemporaryMangedTimeOut*1000)//if we have exceeded the temporary managed mode time
    {
      lightsMode=AUTO;  //revert to auto mode
    }
  }

  if(lcdMode==TEMPO_MANAGED) //if in temporary managed mode
  {
    if(millis()>lcdTemporaryManagedStartTime+lcdTemporaryManagedTimeOut*1000)//if we have exceeded the temporary managed mode time
    {
      lcdMode=AUTO;  //revert to auto mode
    }
  }
}
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

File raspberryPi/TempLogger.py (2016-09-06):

#!/usr/bin/python
# -*- coding: utf-8 -*-

#
#       TempLogger.py
#
#       Copyright 2016 Audrey Robinel - EmNet.cc
#
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

"""This program reads the temperatures of the attached probes and records
it to make statistics.
"""
#import RPi.GPIO as GPIO
import time
import serial
import datetime
import array
import numpy

#__all__ = ['TempLogger', 'run']

class TempLogger:
    'logging temperature for Rlieh'
    __serial_port_name='/dev/ttyAMA0'
    __serial_baudrate=115200
    __serial_timeout=0.05
    __measures_delay=1
    __last_temps_str=None
    __last_temps=array.array('f',[])
    __temps_probes_count=4
    __temp_probes_labels=['eau1','eau2','eau3','air']
    __temps_count=60
    __temps_array=list()
    __max_temps1=array.array('f',[])
    __min_temps1=array.array('f',[])

    __avg_temps_logfile="/mnt/ramdisk/avg_temp_logs.txt"
    #__min_max_reset_time=3600
    #__temps_avg=

    __turn=0
    __reports_interval=6



    def __init__(self):
        for i in range(0,self.__temps_probes_count):
            self.__last_temps.append(-127.0)
            self.__temps_array.append(array.array('f',[]))
            self.__max_temps1.append(-127)
            self.__min_temps1.append(127)
            self.__reports_interval=self.__temps_count

            self.__turn=0

        #self.__temps_array=numpy.zeros((self.__temps_probes_count, self.__temps_count))
        #self.__last_temps_str=None
        #self.__serial_port_name='/dev/ttyAMA0'
        #self.__serial_baudrate=115200
        #self.__serial_timeout=0.05

    def parse_temps(self):
        if(self.__last_temps_str!='' and self.__last_temps_str!='' and self.__last_temps_str!=' '):
            for i in range(0,self.__temps_probes_count):
                self.__last_temps[i]=float(self.__last_temps_str[i*6:(i+1)*6-1])
                #print self.__last_temps[i]

    def print_last_temps(self):
        for i in range(0,self.__temps_probes_count):
            if(self.__last_temps[i]>-127):
                print("%4s=%.2f°C" % (self.__temp_probes_labels[i],self.__last_temps[i]))

    def print_avg_temps(self):
        print ("report : average temps")
        for i in range(0,self.__temps_probes_count):
            print("%4s=%.2f°C" % (self.__temp_probes_labels[i],self.calc_avg_temp(self.__temps_count,i)))
            #print self.calc_avg_temp(self.__temps_count,i)


    def calc_avg_temp(self,nb_mesures,probe_index):
        sum0=0.0
        for i in range(0,nb_mesures):
            sum0+=self.__temps_array[probe_index][i]
        avg0=sum0/nb_mesures
        return round(avg0,2)

    def search_min_temp(self,nb_mesures,probe_index):
        min_t=127.0
        for i in range(0,nb_mesures):
            if(self.__temps_array[probe_index][i]<min_t):
                min_t=self.__temps_array[probe_index][i]
        return min_t

    def search_max_temp(self,nb_mesures,probe_index):
        max_t=-127.0
        for i in range(0,nb_mesures):
            if(self.__temps_array[probe_index][i]>max_t):
                max_t=self.__temps_array[probe_index][i]
        return max_t





    def log_temps(self):
        while True:
            ser =  serial.Serial(self.__serial_port_name, self.__serial_baudrate, timeout=self.__serial_timeout)
            time.sleep(0.1)
            ser.write("getTC:00")
            time.sleep(0.1)
            self.__last_temps_str = ser.readline()
            self.parse_temps()

            #self.print_last_temps()

            #storing values to compute averages
            for i in range(0,self.__temps_probes_count):
                if(self.__last_temps[i]>-127):
                    self.__temps_array[i].append(self.__last_temps[i])
                if(len(self.__temps_array[i])>self.__temps_count):
                    self.__temps_array[i].pop(0)
                    #print self.calc_avg_temp(self.__temps_count,i)



            #print(self.__last_temps)
            #f = open("/mnt/ramdisk/temp_logs.txt", 'a')
            #f.write(str(time.time()))
            #f.write(';')
            #f.write(temps)
            #f.write('\n')
            time.sleep(self.__measures_delay)
            self.__turn+=1
            #print self.__turn
            if(self.__turn>self.__reports_interval):
                self.__turn=0
                self.print_avg_temps()
                f = open(self.__avg_temps_logfile, 'a')
                f.write(str(int(time.time())))
                f.write(';')
                for i in range(0,self.__temps_probes_count):
                    f.write("%.2f°C;" % (self.calc_avg_temp(self.__temps_count,i)))
                f.write('\n')
                f.close()

                f = open("/home/pi/code/min_t.txt", 'a')
                f.write(str(int(time.time())))
                f.write(';')
                for i in range(0,self.__temps_probes_count):
                    f.write("%.2f°C;" % (self.search_min_temp(self.__temps_count,i)))
                f.write('\n')
                f.close()

                f = open("/home/pi/code/max_t.txt", 'a')
                f.write(str(int(time.time())))
                f.write(';')
                for i in range(0,self.__temps_probes_count):
                    f.write("%.2f°C;" % (self.search_max_temp(self.__temps_count,i)))
                f.write('\n')
                f.close()




    def run(self):
        self.log_temps()



def run():
    action = TempLogger().run()

if __name__ == '__main__':
    run()

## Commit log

2014-09-15 base files for testing
    arduino file for the sensor node, and python files for the Raspberry pi
    to test the serial communications to the arduino.
2014-09-18 Fritzing files for circuits
    the basic circuit, controlling two relays, and a DS18B20 temperature
    sensor, is made of an ATMega328p without external crystal (8Mhz).
    The mains lighting is represented by two leds.
    The serial communication with the Raspberry Pi is made with two wires.
    The Arduino Tx is connected to a voltage divider, and goes to the
    Raspberry Pi in order to lower the 5V signal.
    [base_circuit01.fzz]
2014-09-18 Correction of the circuit files, plus images.
    On the previous fritzing circuit file, the ground connection between the
    Arduino and Raspberry Pi was missing. It has now been added.
    I also included a PNG of the circuit, an SVG and a PDF.
    [base_circuit01.fzz]
2014-10-16 full feature prototype files
    This commit includes the fritzing files and pictures (png, jpg, svg and
    pdf) for the shematics of the prototype with all the base features. This
    includes cooling (via fans and/or TEC), lights control (via 2 mains
    relays), water temperature monitoring for 2 tanks and air temperature.
    More features may be added later on, but this is the set of features
    that will be version 1.0 of the system once fully tested.
    [base_circuit02.fzz]
2015-05-26 new files (v2) and php files
    A new version of the files, using the usb serial. Old files are in v1,
    new in v2. There are scripts to turn the lights on and off, the fan on
    and off, read the 2 water temperature sensors, the air temperature
    sensor,
    and also the script that prints the temperatures on the LCD, aswell as
    the script that auto turns the lights on and off.
    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
2015-05-26 rlieh3.ino : arduino file for the USB controller
    This file contains the full code for the Rlieh USB board. Upload this to
    whatever arduino that has enough GPIO and memory (uno, leonardo, mini,
    etc. Basically a atmega328p, a 32u4 or more powerfull), and the heart of
    rlieh is good to go. Now it can listen to serial commands through the
    USB port and return xml-like results.
2015-11-10 basic temp and clock program
    Displays temperature and time using DS18B20 probes and a real time
    module
2016-03-22 Front of the control box
    This scad file can be adjusted to set with, length, height, and the number of buttons.
    It is meant for a 4x20 LCD.
    [controlBox.scad]
2016-03-22 Front of the control box, stl ready for printing
    The stl file, ready for printing for the front part of the control box.
    [controlBox.stl]
2016-03-22 Increase of holes diameter for an easier fit.
    [controlBox.scad, controlBox.stl]
2016-03-23 Missing file required to compile the case
    [textLcdBezels.scad]
2016-03-24 size adjustment in scad file
    [textLcdBezels.stl]
2016-04-06 starting camera skirt developpement
    starting camera skirt development, added a module for that part
    [enclosure.scad]
2016-08-19 Source code for the 1.0 Arduino file
    This is the source code for the Arduino part of Rlieh. It was developped with an Arduino nano V3, and should be compatible with uno boards. It should work with leonardo boards and mega boards to, but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
2016-08-19 stl files for the box, with two layers.
    The facebox is the first layer, for the LCD and the buttons, whereas the faceBox_layer2 file is for the second layer, for the arduino board and the raspberry pi. The piZeroSimpleSupport file is the s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
    [faceBox.stl, faceBox_layer2.stl, piZeroSimpleSupport.stl]
2016-09-05 V1.0 of the Arduino code
    This code must be uploaded on the Arduino Nano that runs the controller.
2016-09-05 improvement on the second layer+printable buttons
    this version improves the second level of the box, cleans the code in some places, and adds printable button that can contain an RGB LED for backlit buttons near the LCD. The PCB support has been imp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
    [faceBox.scad]
2016-09-05 Improved second layer of the box, for pi zero
    [faceBox_layer2.stl]
2016-09-05 files for the RGB lit buttons
    the frontLedDiffuserButton parts must be printed in clear plastic, all the others can be printed in any color.
    [frontLedDiffuserButton.stl, frontLedDiffuserButtonBack.stl, frontLedsDiffuserCenteringPlate.stl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]
2016-09-05 supports for the pi Zero
    this is the same part, but it's flipped to change the position of the pi in the case. the piZeroSimpleSupport is the default one.
    [piZeroSimpleSupport.stl, piZeroSimpleSupportBottom.stl]
2016-09-06 TempLogger python class initial commit
    This class is used to log temperatures measured by rlieh and log it, as well as making statistics.
2016-09-06 sorted files
    files were not sorted properly in the project
    [controlBox.scad, controlBox.stl, enclosure.scad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]
2016-09-06 further project sorting and cleaning
    moved some files, deleted some un-needed ones (there are still old
    useless files laying around)
    [controlBox.scad, controlBox.stl, enclosure.scad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]

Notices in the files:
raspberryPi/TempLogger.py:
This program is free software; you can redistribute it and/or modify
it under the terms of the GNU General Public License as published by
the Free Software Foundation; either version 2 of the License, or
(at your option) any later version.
